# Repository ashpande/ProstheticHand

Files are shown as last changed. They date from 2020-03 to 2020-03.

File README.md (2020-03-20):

# Prosthetic Hand

This project is a prototype for an affordable, modular, myoelectric prosthetic arm. It was one of the entries for Dassault Systemes Aakruti Design contest 2019 and came among the top 3 in the south zone regionals in India among 5000+ teams. It is made out 3D printed ABS plastic and uses TPU material for joints. A detailed description of the project and its features can be found in the DIY report of this repository and the Powerpoint Presentation. All the CAD files are in SolidWorks and can be used to 3D print the prosthesis in any 3D printer.

The electronics component for myoelectric control is still under development, and the repository will be updated when it is done.

## Prosthetic Schematics

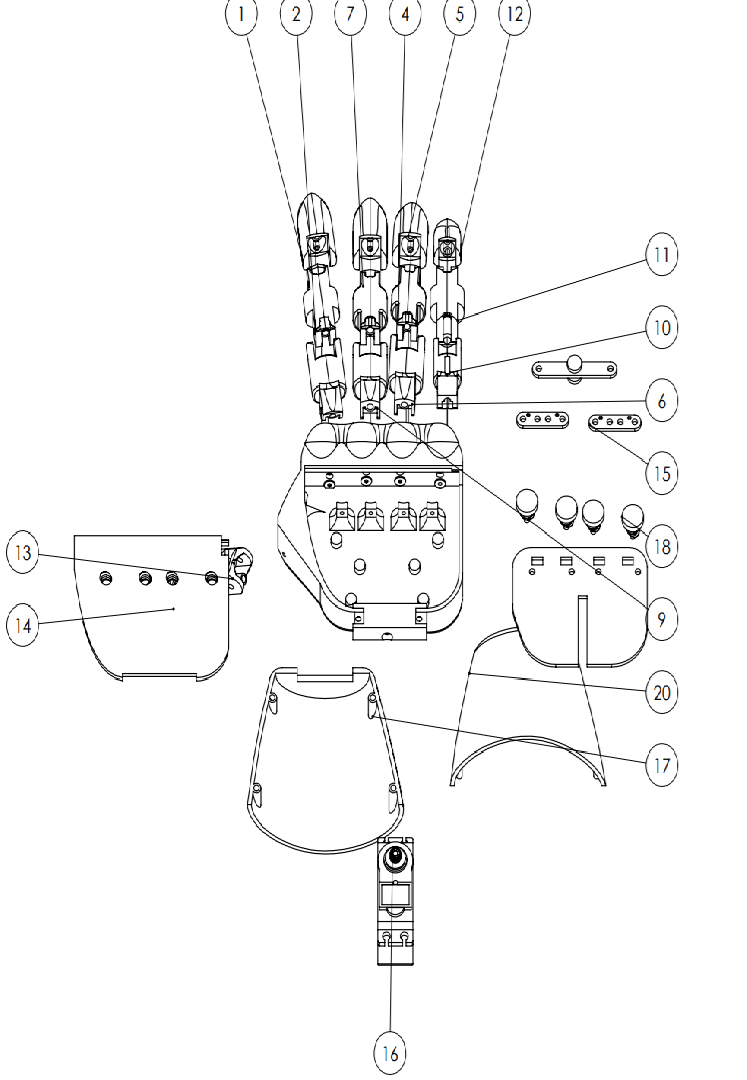
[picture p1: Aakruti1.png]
Prosthetic Hand Schematic


| Part Number | Name |
| ---| ---- |
| 1  | INDEX FINGER DISTAL|
| 2  | INDEX FINGER MIDDLE|
| 3  | INDEX FINGER BOTTOM PROXIMAL|
| 4  | RING FINGER MIDDLE |
| 5  | RING FINGER DISTAL |
| 6  | RING FINGER BOTTOM PROXIMAL |
| 7  | MIDDLE FINGER MIDDLE |
| 8  | MIDDLE FINGER DISTAL |
| 9  | MIDDLE FINGER BOTTOM PROXIMAL|
| 10 | PINKY FINGER PROXIMAL|
| 11 | PINKY FINGER MIDDLE|
| 12 | PINKY FINGER DISTAL|
| 13 | THUMB PROXIMAL|
| 14 | THUMB TIP|
| 15 | PALM FRAME BODY|
| 16 | STANDARD SERVO|

## Render
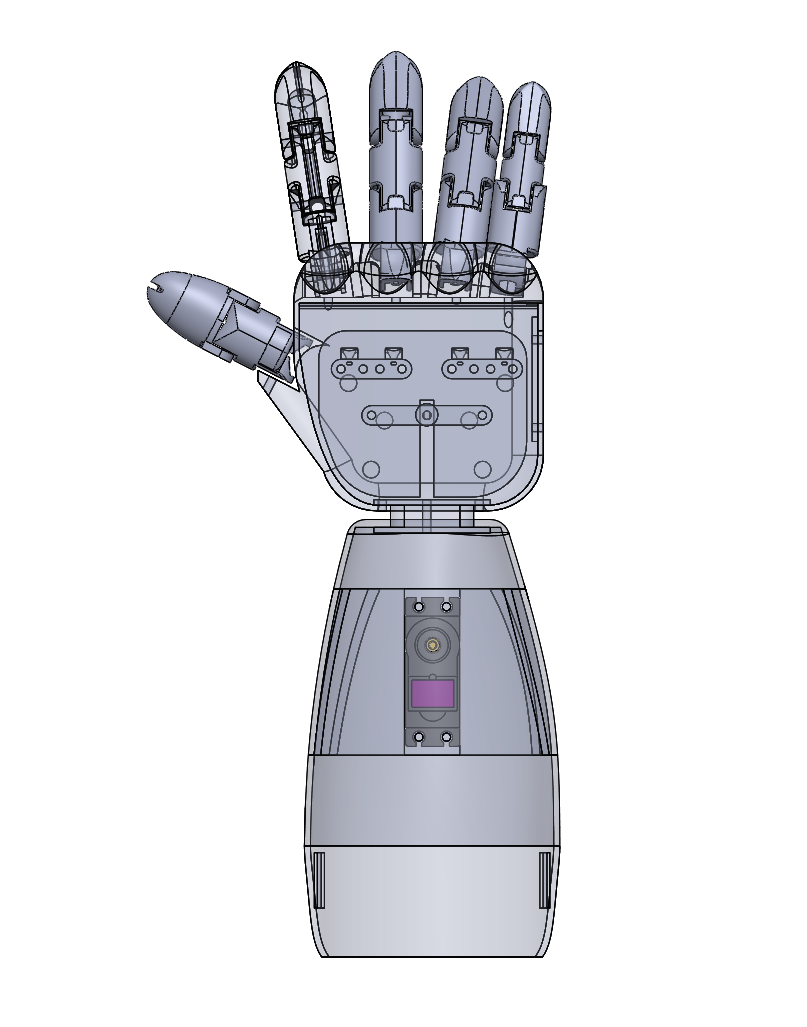
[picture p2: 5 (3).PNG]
Prosthetic Hand Render


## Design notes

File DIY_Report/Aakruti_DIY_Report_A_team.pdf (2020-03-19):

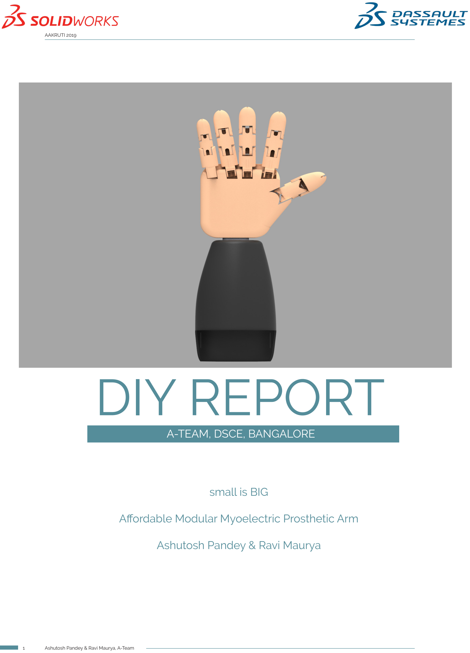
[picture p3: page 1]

1 | Ashutosh Pandey & Ravi Maurya, A-Team

AAKRUTI 2019

### A-TEAM, DSCE, BANGALORE

# DIY REPORT

### small is BIG

### Affordable Modular Myoelectric Prosthetic Arm

### Ashutosh Pandey & Ravi Maurya

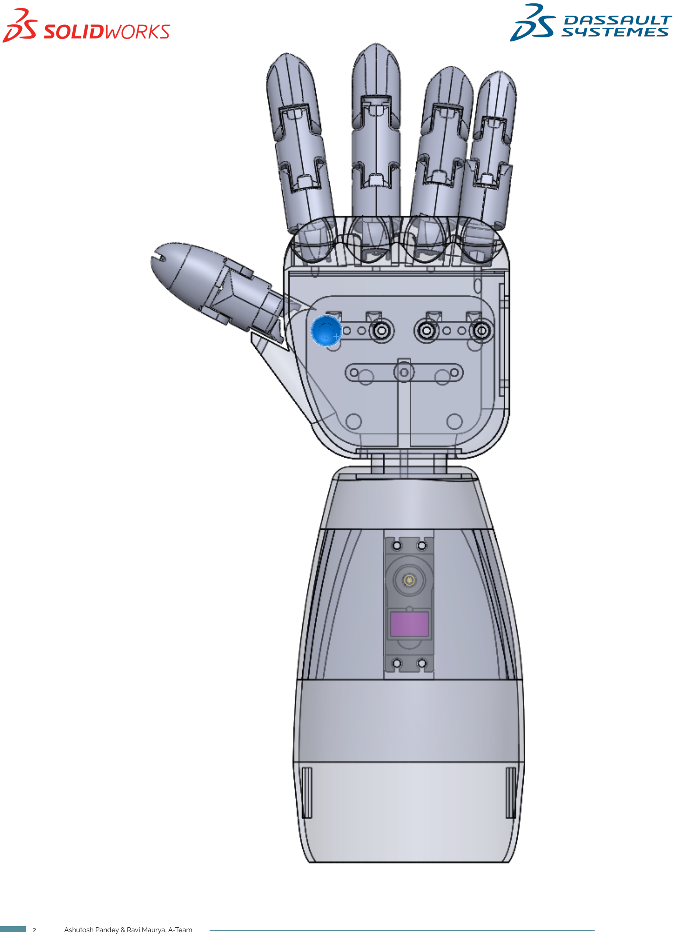
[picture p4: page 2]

### Problem Statement Market Analysis Shortcomings in Commercial Products Our Solution Design Details Product Development Cycle Analysis and Calculations Iterations of our Design Raw Materials Bill of Materials and Costing Report Electronics Assembly and Manufacturing Drawings References

## Table of Contents

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
# Problem Statement

- A multifunctional, modular, myoelectric prosthesis.

### Prosthesis

Prosthetics are artificial limbs that can be used by people who have lost their limbs, or are born with natural deformities. While the foot prosthesis has made remarkable strides in functionality and affordability with the Jaipur leg costing as little as $40, there is no such equivalent for the upper body prosthesis. Moreover, the alternatives that do exist have severe shortcomings when it comes to pinch force, grip strength and mass.

One major reason for this lack of development in upper body prosthesis is due to the complexity of the human hand itself - It has 27 degrees of freedom and it is both strong and dexterous. A need exists for an upper body prosthesis that is cheap, functional, easy to use and lightweight.

### Types of Prosthesis

There are primarily three types of upper body prosthesis in the market today:

### 1. Cosmetic Prosthesis: these prosthesis

do not offer any functionality. They are very cheap.

### 2. Body Powered: these are manipulated by

hooks and cables attached to the body. While they are also inexpensive, they require a lot of power from the user to move successfully. They also offer very little grip force and pinch strength. They are limited to opening and closing motions of the palm.

### 3. Myoelectric: these are controlled by

electrical signals from the arm stump. They do not require any force to be exerted by the user, can replicate a variety of movements but are extremely expensive ($15,000 and up).

# 50 lakh

### amputees in

India.

₹1.5 L

### Cost for a semi functional

prosthesis.
50%

### people don’t wear their pros-

thesis regularly.

27

### Degrees of Freedom in the

human hand.

400 g

### Average weight of a human

hand.

The Global Prosthesis Market According to a survey by Future Market Insights (FMI), upper body prosthesis are predicted to grow at a Compounded Annual Growth Rate (CAGR) of 4.8 %. The market is primarily dominated by 4 companies: Ottobock, Ossur, Fillauer and Blatchford.

North America and Europe account for 55% of the sales, while India makes up less than 10% of the current $330 million upper body prosthesis market. This despite India having over 50 lakh amputees, and adding over 24,000 new amputees every year, shows that the uptake of upper arm prosthesis in India has been very slow.

The current offerings in the market are prohibitively expensive, In USA a part of the prosthesis cost is borne by the Insurance companies, despite this the costs go from $15,000 to over $90,000. The cheapest Indian alternatives also cost over ₹1.5 Lakh, putting them out of reach of economically disadvantaged individuals who lose out on their livelihoods due to their disabilities.

25% of the demand is for below the elbow prosthesis, while the demand for myoelectric prosthesis is 40%.

In India a few popular options are the Ottobock Body powered arm that uses hooks and cables and costs ₹1.5 lakh, the Myofacil Myoelectric arm that costs ₹2,36,000 and can perform a few movements after training, and the upper segment has the Bebionic prosthetic arm, which costs over ₹10,00,000 and can replicate lots of movements.

# Market Analysis

- A global 1.2 billion USD market for prosthesis exists.

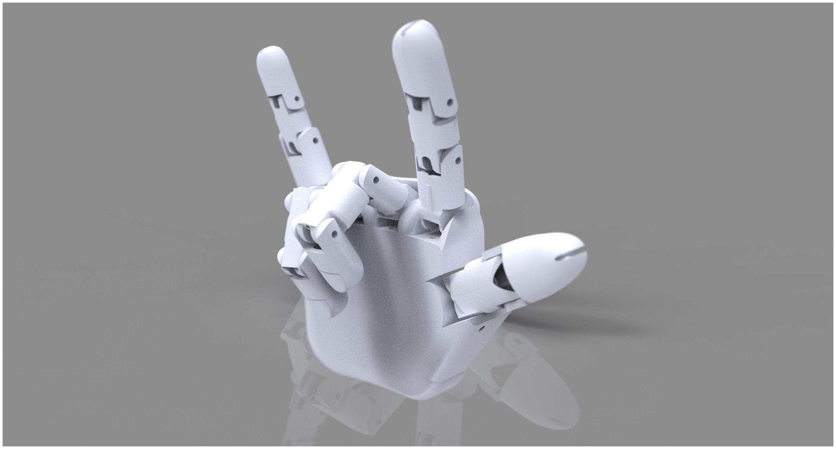
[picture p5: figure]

Modern day prosthesis are
plagued by a whole host
of problems apart from the cost, we shed some light on these shortcomings below:

Pinch Force and Grip
Strength: a person needs
to be able to lift objects with their prosthetic arm. Studies recommend a bare minimum of 45N of grip force,
with 65N being the optimum.

Weight: The average human

hand weighs 400 grams.
Myoelectric prosthesis can weigh upto 1.5Kg, which
makes them too uncomfortable to use and wear for extended periods of time.

Cost: Unlike the ubiquitous Saathi and Jaipur leg, there is no cheap upper arm prosthesis in India. The most
common type of prosthetics used by Indians are the cosmetic ones, which help
with the social stigma but do not objectively improve the quality of life.

Non Modular: Upper arm
prosthesis tend to wear out in 5 years. This makes them an expensive, recurring investment. The tips of the fingers are particularly prone to wear and tear, and currently the entire prosthesis must be replaced in such a case. Moreover, children often outgrow their prosthesis and have to buy new ones.

An average hand can exert upto 95 N of force in a precision grip. For a prosthesis to be functional, it has to be able to manage atleast 50% of that grip strength, which almost all prosthesis fail to do. There has been very little progress in upper arm prosthesis research in 40 years.
- Study by TU Delft.

# Shortcomings

## - In the current market offerings

Our product costs less than ₹15,000 to manufacture using 3D printing technology which is fast becoming ubiquitious in India. It is lightweight - weighing in at only 372 grams. This is made possible by the use of generative design in the fixtures. We use cheap, off the shelf myoelectric sensors and make the design modular to be able to easily replace worn out parts.

### 32 distinct combinations

Our whiffletree mechanism
allows our arm to have 32
distinct combinations of
positions.

Modularity
Our arm consists of distinct modules which can be easily swapped out.

Myoelectric control
We use myoelectric control powered by an inexpensive
sensor to make the product easy to use.

# Our Solution

- A multifunctional, modular, myoelectric arm.

Our Product
We studied the various prosthesis in the market, referred to research papers by leading universities and medical journals, and finally chose to use 3D printing technology for our prototype because it allows us to quickly test out variations of the design.

Keeping the Indian weather conditions in mind, ABS was chosen as the material because of its greater tolerance to heat and higher strength.

The Whiffletree is a mechanism to distribute force evenly through linkages. In our prosthesis, it allows us to make different positions and combinations using only 1 servo and that is the reason it was chosen.

Keeping the weight low was important to making the product more useable and to reduce cost. We used generative design in the servo fixtures to reduce the weight.

Body powered prosthesis require a lot of hooks and cables, and ultimately provide a worse user experience because they require so much force to operate. Keeping this in mind, we decided to opt for myoelectric control over making a purely mechanical design. We used commercially available components to bring down the cost and reduce the time to market.

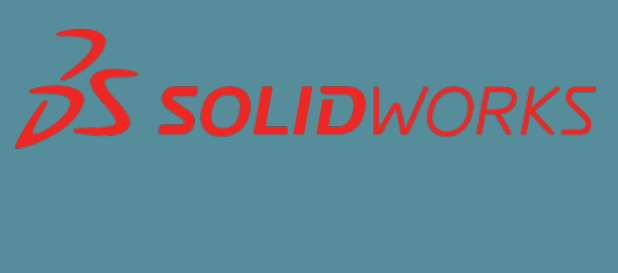
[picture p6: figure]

Fingers
One single finger was the
starting point for the entire design process. The human
hand consists of four similar fingers and one thumb, it was logical to conclude that the finger design could potentially be replicated four times. The finger design process began with determining what motion was required
for each finger. The human hand was simply viewed
gripping various household objects such as a cup and
marker commonly found in
a person’s daily routine. The location of the various joints were measured and translated to drawings.
The human finger is an
amazing piece of engineering consisting of three individual pivot joints which can almost be individually actuated through muscular tendons.

The Thumb
The thumb has also been
designed in a similar fashion. Most commercial and research prosthetic hands
aim to provide at least three degrees of freedom in the
thumb.
This thumb however only
provides a two degrees of
freedom – it can only open/ close in a single way. Guide holes have been incorporated into the design of the fingers and thumb to optimise tendon orientation and prevent the tendon lines from getting caught on a sharp
edge.

The Palm
Each finger connects to the palm by pins. The palm accommodate:
1) the finger base frames,
2) the selectively lockable differential mechanism

The design of the proposed differential mechanism is
motivated by the fact that humans develop over their
lives a tremendous ability to select the most appropriate grasping strategy for a given task. A well known differential mechanism is the whiffletree , which is typically used to interconnect the
index, middle, ring and pinky fingers of underactuated,
multifingered robot
hands.

# Design Details

## We use a bottom-up design methodology

### The Fingers

are the basic unit of
articulation.

### The Thumb

Humans have opposable
thumbs.

### The Palm

Houses the selectively lock- able differential mechanism.

### Fingers

4

### Thumb

1

### Palm

1

The prototype went through iterations where it was tested, upgraded and independently ana- lysed critically. This helped us make the end product lighter, more efficient and easier to use and maintain.

# Identify the problem

Market Value | Responsibility

Our product design cycle
starts with research into
the problem statement.

### Effectiveness

How effective are the solutions in the market? Do
they adress the need of
the users? is there scope
for improvement?

Different Approaches
What are the dif- ferent design phi- losophies that can

be used? Different
m a n u f a c t u r i n g
processes?

Scalability

How labour inten- sive is the manu- facturing process?

Can it be mass
produced easily?

Upgradeability

Can the product
be easily upgrad- ed? Can it be done

in a cost effective
manner?

Profit

Can the product
be sold for a sus- tainable profit?

Does the revenue
model account for
losses?

Is there an untapped
market for the product?
How much is the industry worth currently? Is the product going to increase
in demand?

Does the product help improve the quality of life for its users? Can it be sold
ethically without short
changing the consumer?

# Product Development Cycle

## A few questions that we asked ourselves

# Calculations

The weight that could be supported by the fingers was calculated.

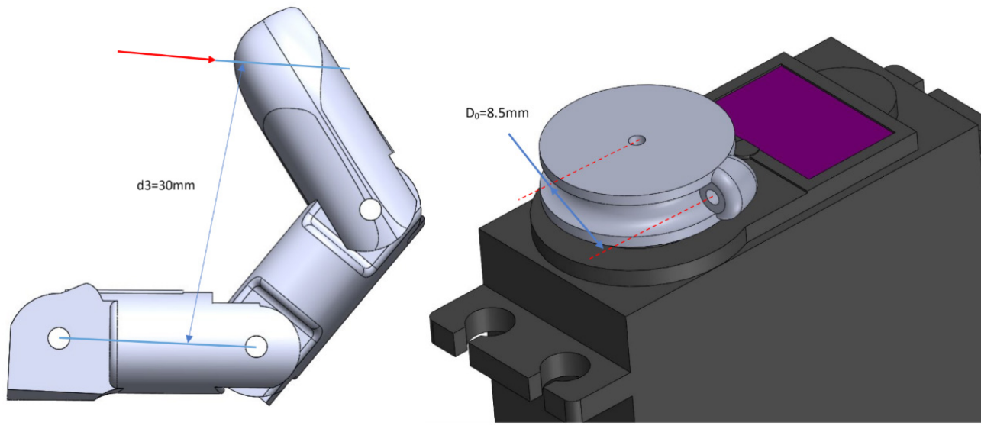
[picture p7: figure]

135 grams is the mass that each finger can lift when it is fully extended. When the fist is closed, the force applied to the index finger acts normal to it, and each finger can lift a total of 320 grams for a lifting capacity of 1280 grams.

When the finger is fully extended, force is applied at the tip (distal) end of the finger. The movement is given by the expression:

The given torque of the servo we use:

Tendon creates a moment about each joint in the finger. Since knuckle joint is the furthest from the applied force the moment about it will be the greatest. At maximum lift M1=M2. The stall torque (maximum turning force) of the OC Servo A091 is 9Kg-cm at 6v. This stall torque will be transferred equally in all 5 fingers.

135 grams is the mass that each finger can lift when it is fully extended. When the fist is closed, the force applied to the index finger acts normal to it, and each finger can lift a total of 320 grams for a lifting capacity of 1280 grams.

# Analysis

- We confirmed our hand calculations with analysis.

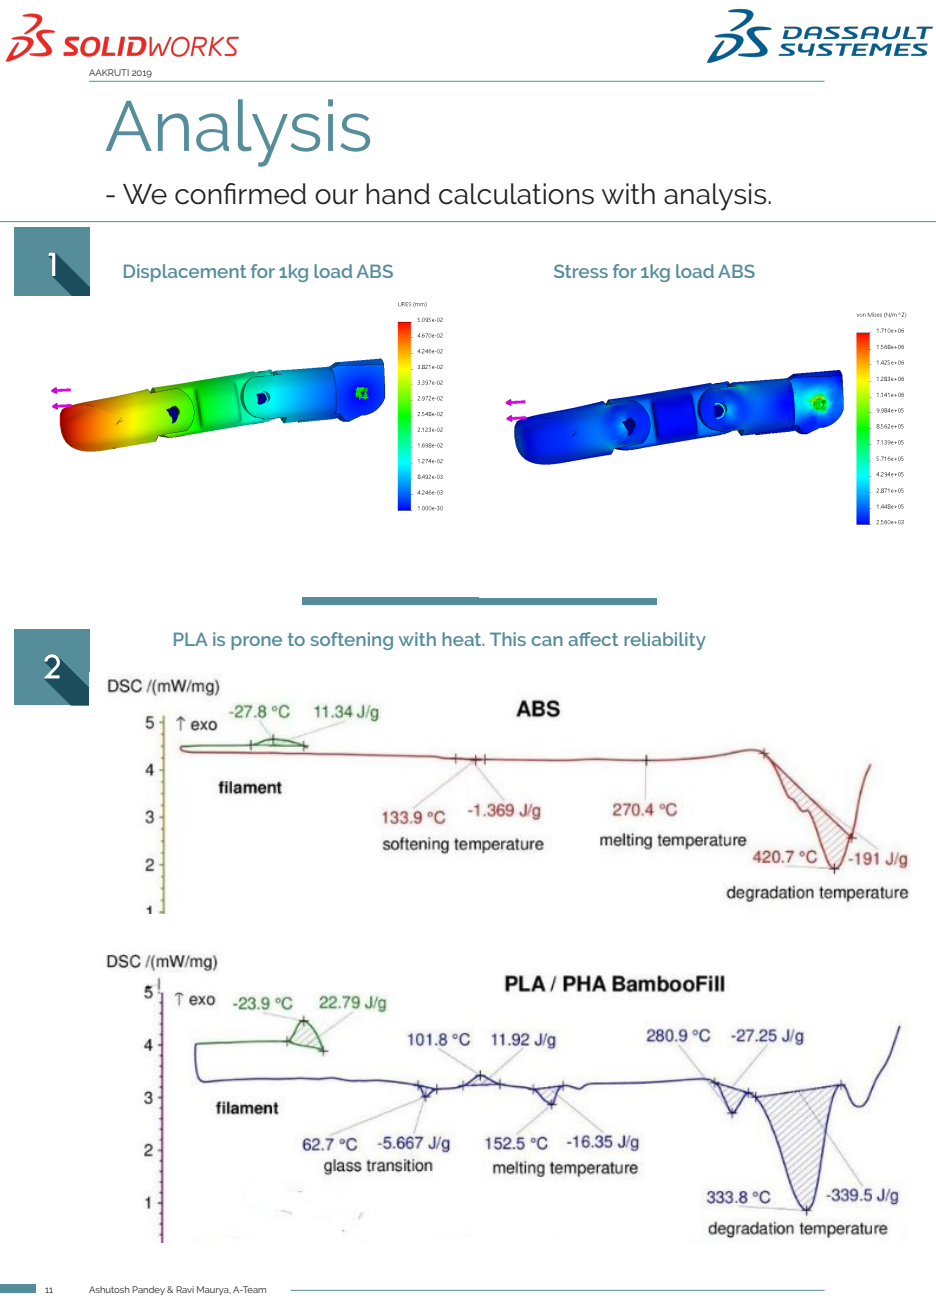
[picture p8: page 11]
Displacement for 1kg load ABS; Stress for 1kg load ABS

PLA is prone to softening with heat. This can affect reliability

# Design Iterations

## - 3 prototypes were made in total

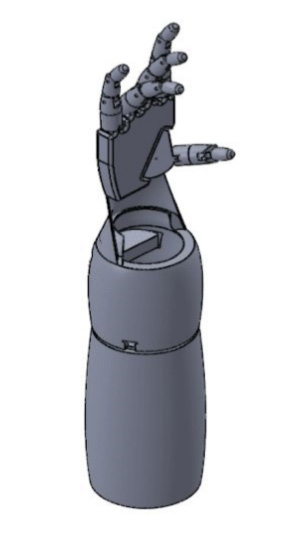
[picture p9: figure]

The First Prototype

The first prototype was made for the initial concept submission phase. This prototype had the following shortcomings/features:
- The prototype could only open/close the fist.
- There were no buttons or whiffletree mechanism.
- The 5 fingers were directly connected to different servos.
- It was rather heavy 725 grams.

The Second Prototype

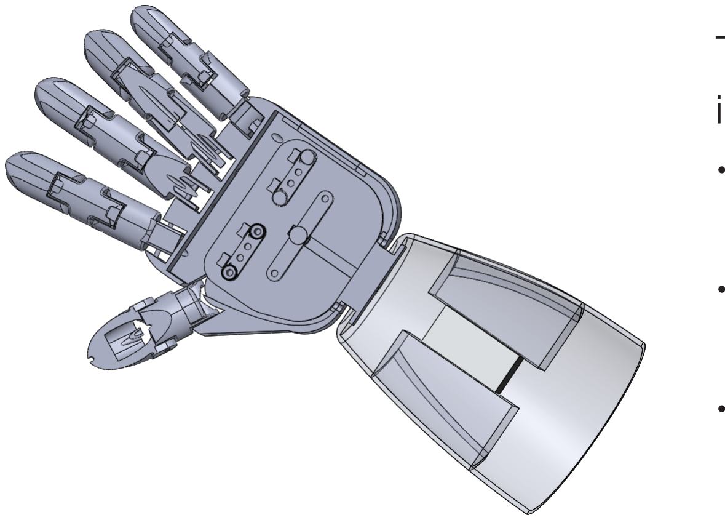
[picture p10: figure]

The second prototype was made for the zonal round in Chennai. This prototype featured improvements:
- The whiffletree mechanism was chosen to reduce the complexity of the electronics.
- TPU material was chosen for the joints to act as tendons, because of its elasticity and durability.
- During manufacturing it was found that the fingers needed repositioning and tolerances were needed.

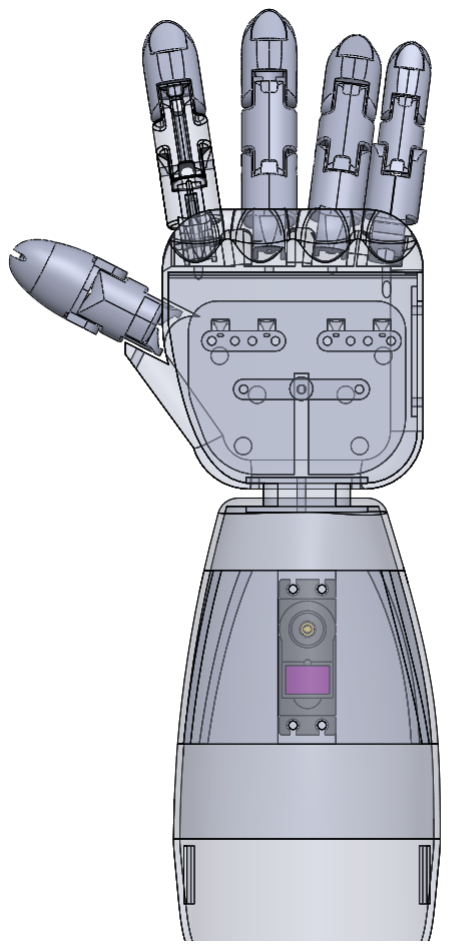
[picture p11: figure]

The Third Prototype

The third prototype was made for the finals of Aakruti 2019. This features a number of improvements over the second version:
- The fingers were repositioned to make them move more freely.
- Tolerances were considered during 3D printing to make manufacturing easier.
- The thumb was redesigned to have means to connect to a second servo, as the human thumb is opposable and free to move and thus, operates independently of the rest of the hand.

# Raw Materials

## - After much experimentation, we chose these

ABS - Acrylonitrile Butadiene Styrene

z High Strength

z High Glass Transition temperature

z Smooth Finish and can be 3D print

TPU - Thermo Plastic Polyurethane

z Used as an artificial tendon

z Flexibility and elasticity

z Durability- lasts a long time

Nylon Thread

z To transfer force from the servo to fingers

z Resistant to heat

z Durable

Acetone

z Is used to work the ABS to a smooth finish.

Cyanoacrylate Glue

z To glue together different components,

z Cures fast.

z Strong bond.

# Bill of Materials

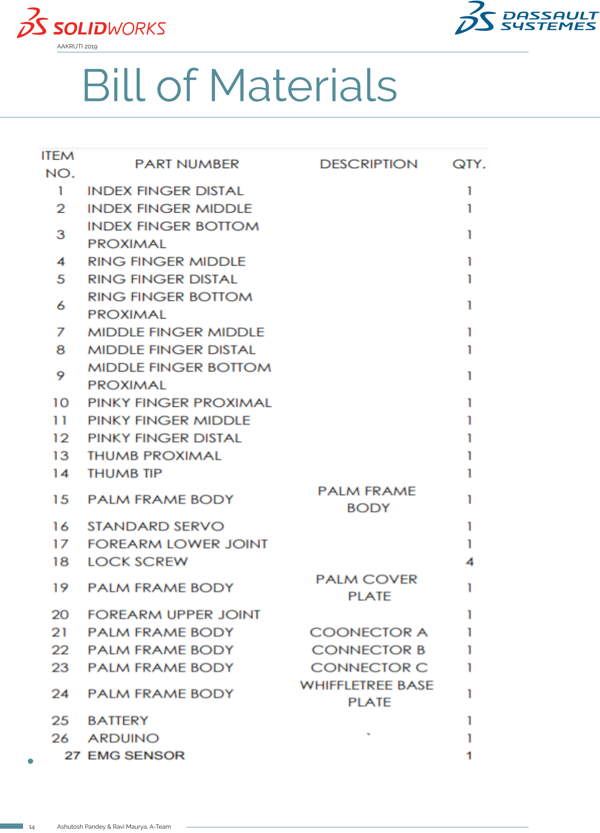
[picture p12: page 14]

z

# SolidWorks Costing Report

# EMG

Electromyography is used to read signals from the arm.

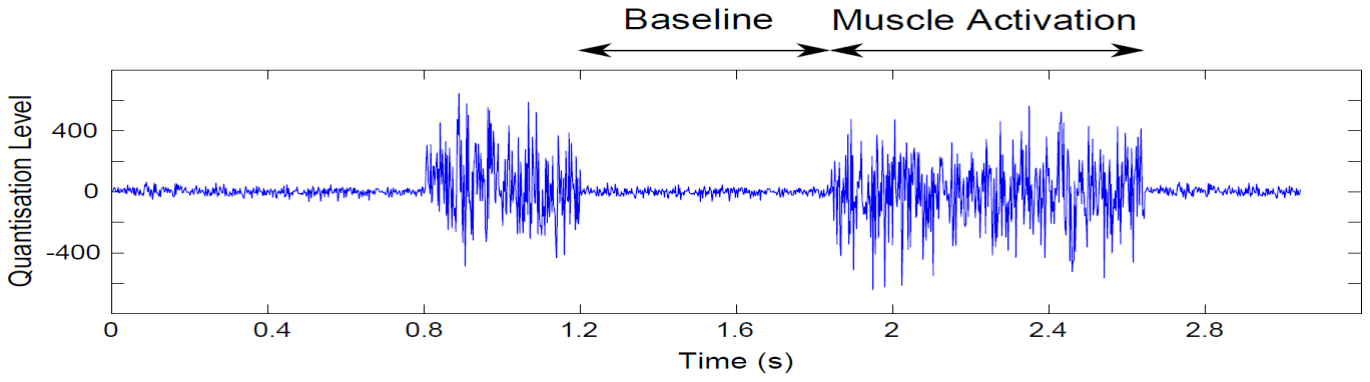
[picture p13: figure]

All animals have muscles that contract by means of electrical activity - it is well known that the brain sends electrical impulses to the motor neurons in the arm which causes muscle fibers to contract. It is easy to measure this contraction of muscle fibers from surface electrodes, this is known as electromyography.

Procedure
For the purpose of the prototype, we use a Myoware sensor which costs $37. The sensor has a pair of snap on electrodes attached to it. Currently these electrodes are one time use only - we are undertaking research on how to use reusable electrically conductive cloth.

The electrodes are placed at specific spots above the stump of the arm. There are three electrodes - Two electrodes at the ends of a muscle fiber, and one reference electrode which is normally attached to the underside of the arm.

When the consumer flexes their arm, it generates an electrical signal that is picked up by the sensor.

The sensor is connected to a microcontroller, which processes the signal and controls a servo. Practically any microcontroller can be used for this, although we use an AT-MEGA328P as it is common, cheap and fast enough to do the job real time.

The servo we use is a high torque 9kg-cm servo that provides the prosthesis a lifting capacity of upto 1.3 kg, this is no mean feat as n0rmal prosthesis are able to lift nowhere near this amount.

The whole setup is powered by a battery, at full load the system can last around 8 hours of use on a 2200 mAh battery. The battery can be recharged at night when the prosthesis is disengaged.

Electromyography is an electrodiagnostic medicine technique for evaluating and recording the electrical activity produced by skeletal muscles. In our prototype, we use EMG Sensors attached to the stump of the arm and measure the change in potential with contraction of muscle fibers, and use this signal to control our prosthetic hand.

# Circuit Diagram

The following circuit diagram is made on fritzing.

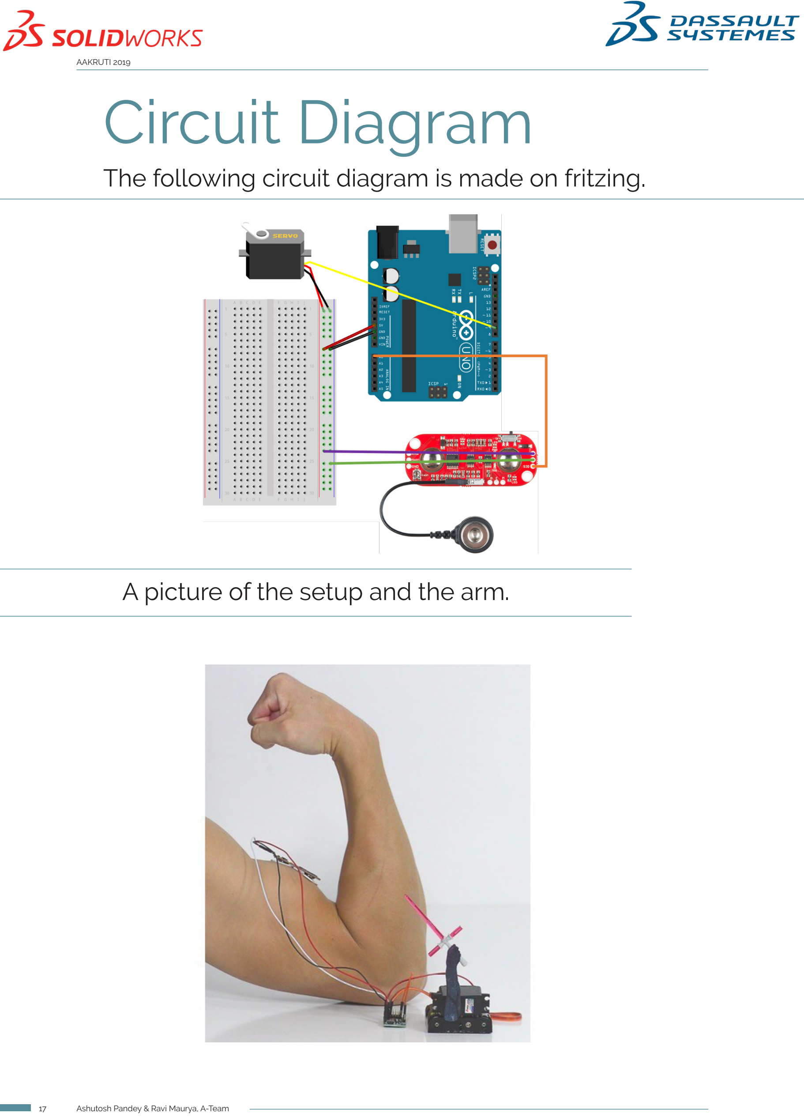
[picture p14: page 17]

A picture of the setup and the arm.

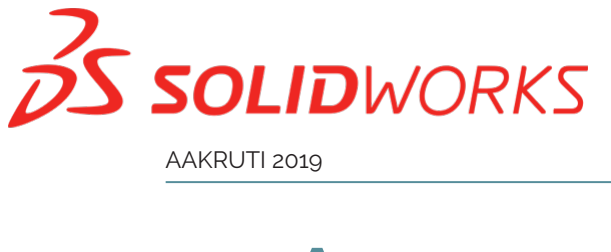
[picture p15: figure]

# Assembly

- Each finger consists of
three individual printed parts connected by
polypropylene pins. all
the 4 fingers along with

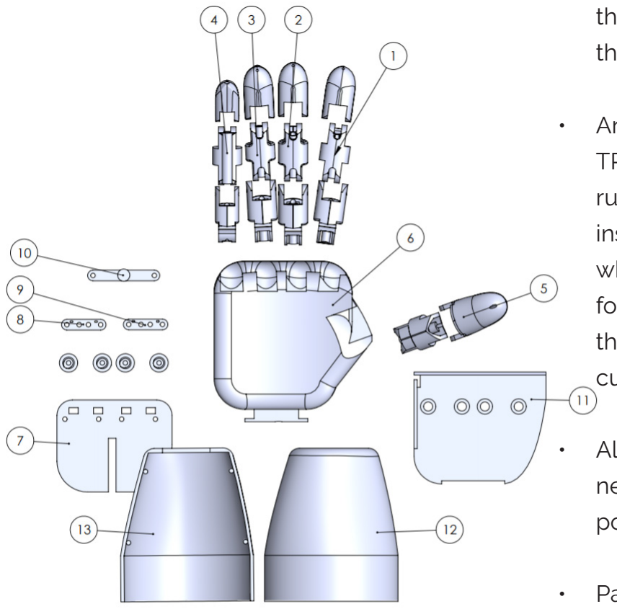
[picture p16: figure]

thumb are connected in
the same way.
- Artificial tendon loops of TPU and nylon thread
runs through channels
inside the finger which
when pulled rotational
forces are applied to all
the joints and fingers
curls up.
- All the fingers are connected to the palm by
polypropylene/abs pins.
- Palm accommodates
the differential mechanism (Whiffletree mechanism) Which consists of
the component such as
bar A(8) and bar B (9).
- Bar A connects index and

middle finger whereas
bar B concepts ring and
pinky.
•
- The top two bars of our
whiffletree have appropriately designed holes
and the palm accommodates a set of buttons
that upon pressing are
elongated.
- When | a | button | is
pressed the elongated
part fills the corresponding finger hole and the
motion of this particular
finger is constrained.

# Manufacturing Drawings

1 | 2 | 7 | 4 | 5 | 12

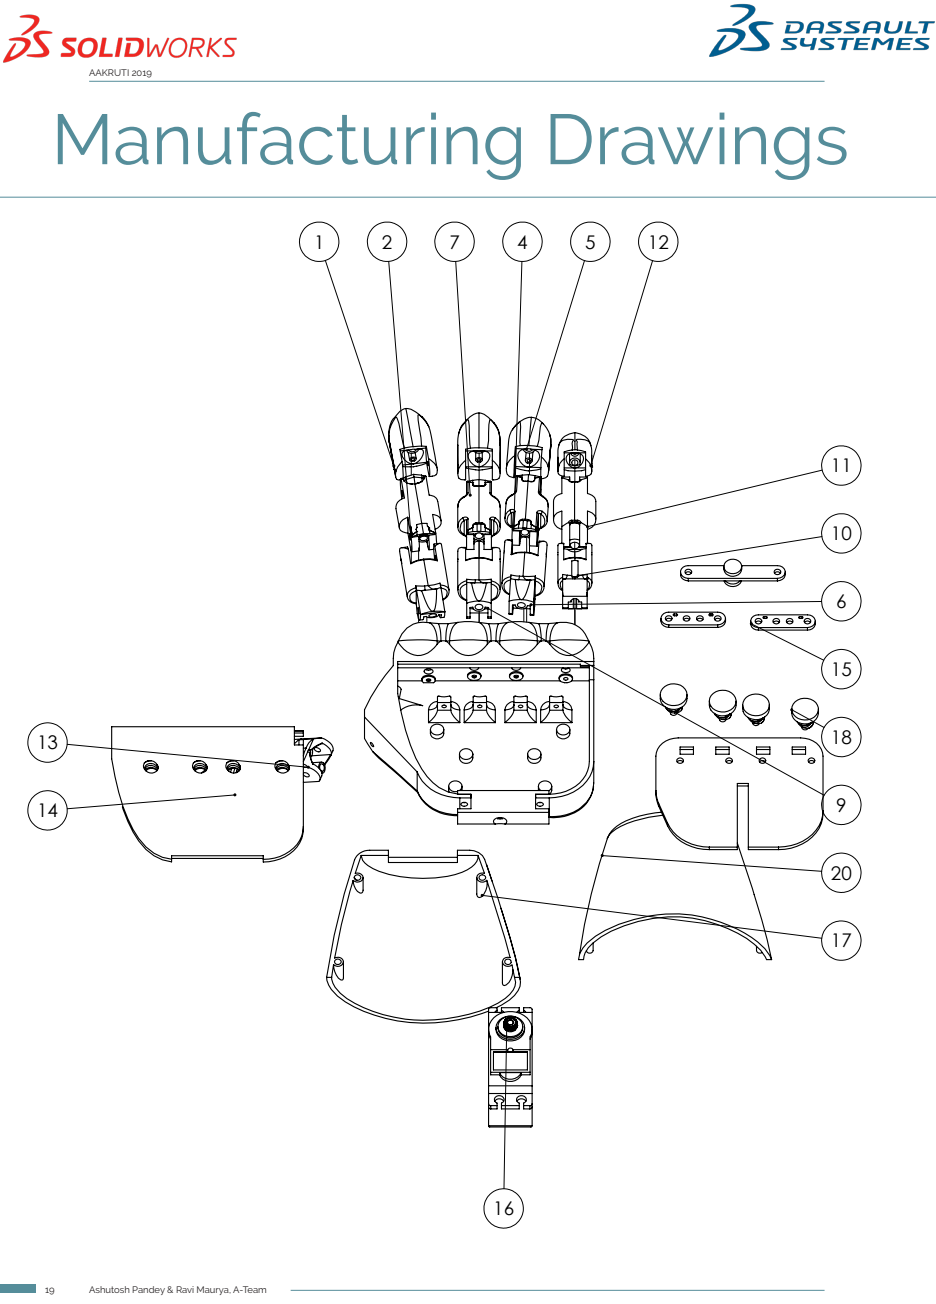
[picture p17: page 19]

# Manufacturing Drawings

## ITEM

NO. | PART NUMBER | DESCRIPTION | QTY.
1 INDEX FINGER DISTAL | 1
2 INDEX FINGER MIDDLE | 1

## 3 INDEX FINGER BOTTOM

| PROXIMAL | | 1
4 RING FINGER MIDDLE | 1
5 RING FINGER DISTAL | 1

## 6 RING FINGER BOTTOM

| PROXIMAL | | 1
7 MIDDLE FINGER MIDDLE | 1
8 MIDDLE FINGER DISTAL | 1

## 9 MIDDLE FINGER BOTTOM

| PROXIMAL | | 1
10 PINKY FINGER PROXIMAL | 1
11 PINKY FINGER MIDDLE | 1
12 PINKY FINGER DISTAL | 1
13 THUMB PROXIMAL | 1
14 THUMB TIP | 1
15 PALM FRAME BODY | PALM FRAME
| | BODY | 1
16 STANDARD SERVO | 1
17 FOREARM LOWER JOINT | 1
18 LOCK SCREW | 4
19 PALM FRAME BODY | PALM COVER
| | PLATE | 1
20 FOREARM UPPER JOINT | 1
21 PALM FRAME BODY | COONECTOR A | 1
22 PALM FRAME BODY | CONNECTOR B | 1
23 PALM FRAME BODY | CONNECTOR C | 1
24 PALM FRAME BODY | WHIFFLETREE BASE
| | PLATE | 1
25 BATTERY | 1
26 ARDUINO | ` | 1

# Manufacturing Drawings

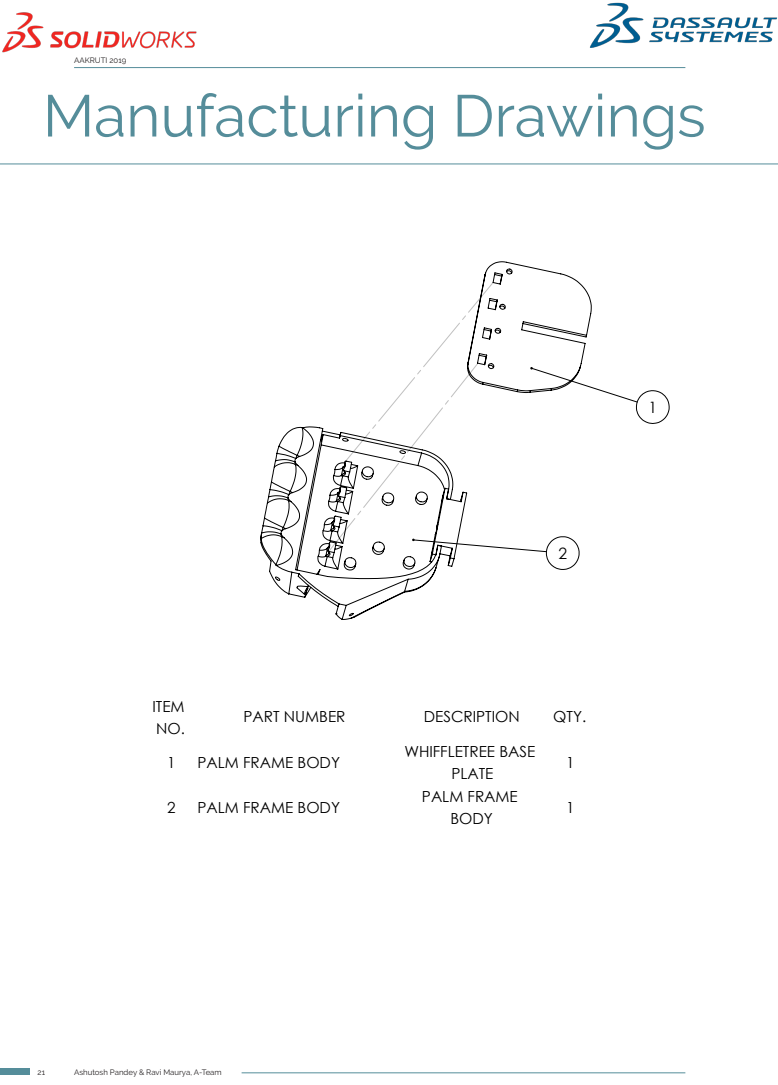
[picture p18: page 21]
ITEM; PART NUMBER; DESCRIPTION; QTY.; 1 PALM FRAME BODY; WHIFFLETREE BASE; PLATE; 2 PALM FRAME BODY; PALM FRAME; BODY

# Manufacturing Drawings

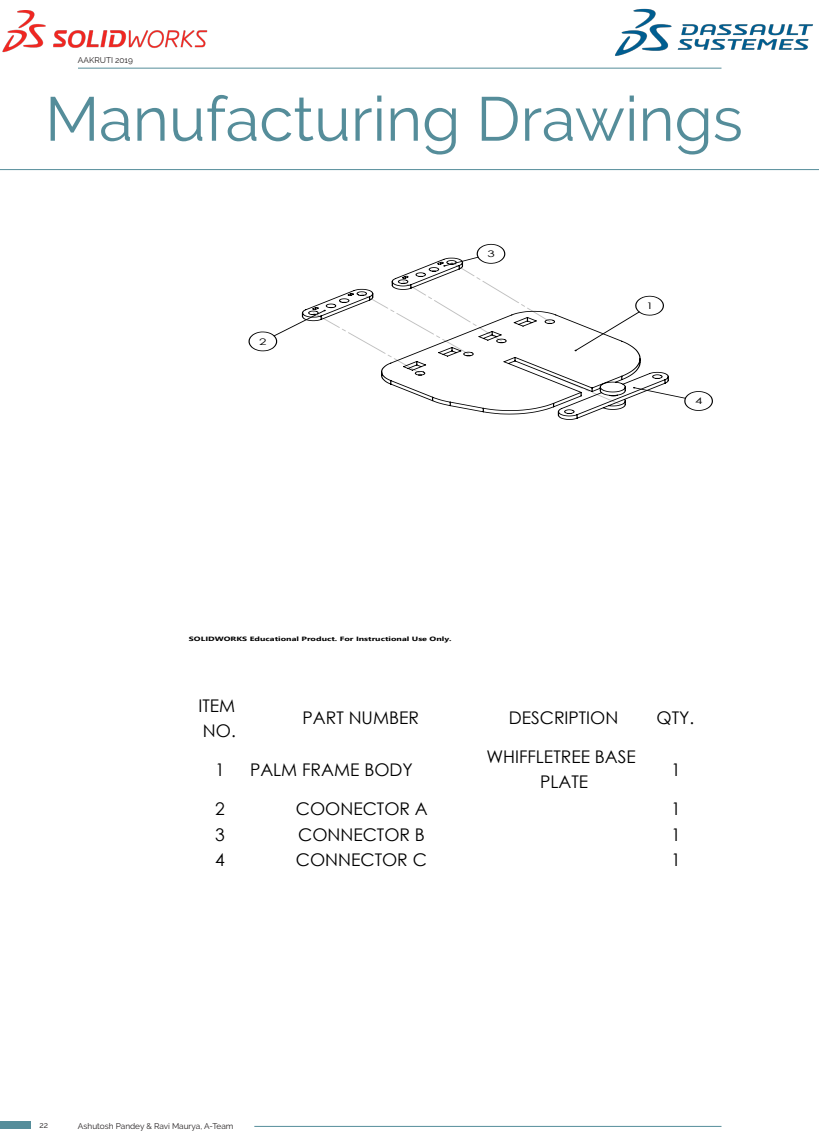
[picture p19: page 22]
ITEM; PART NUMBER; DESCRIPTION; QTY.; 1 PALM FRAME BODY; WHIFFLETREE BASE; PLATE; COONECTOR A; CONNECTOR B; CONNECTOR C

SOLIDWORKS Educational Product. For Instructional Use Only.

# Manufacturing Drawings

2

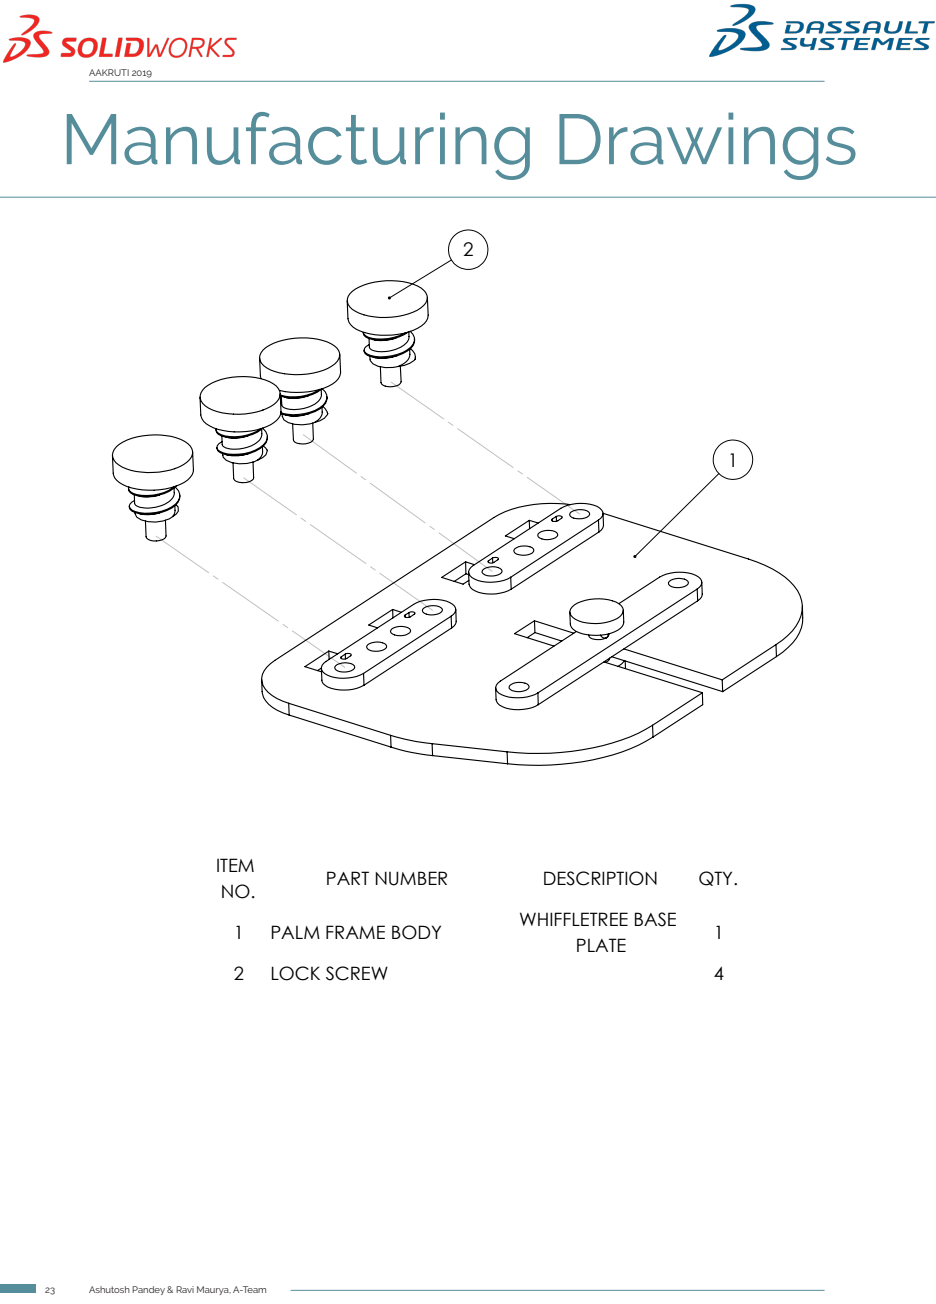
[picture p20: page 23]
ITEM; PART NUMBER; DESCRIPTION; QTY.; 1 PALM FRAME BODY; WHIFFLETREE BASE; PLATE; 2 LOCK SCREW

# Manufacturing Drawings

1

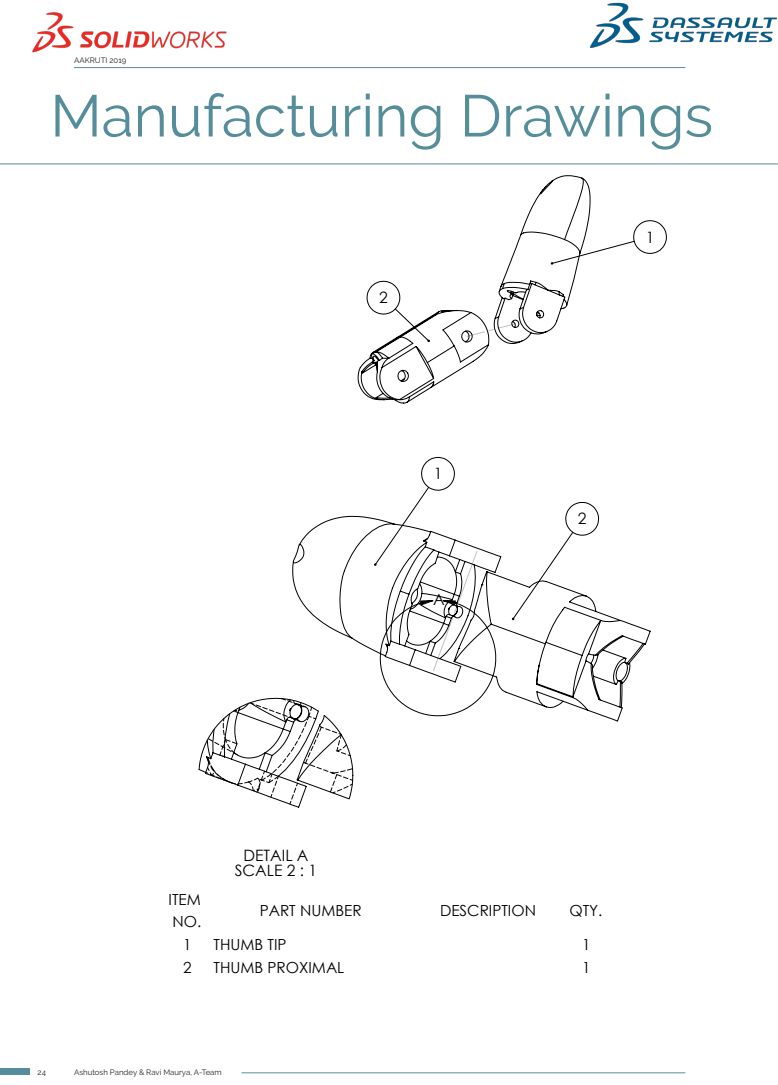
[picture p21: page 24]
ITEM; PART NUMBER; DESCRIPTION; QTY.; 1 THUMB TIP; 2 THUMB PROXIMAL; DETAIL A SCALE 2 : 1

# Manufacturing Drawings

1

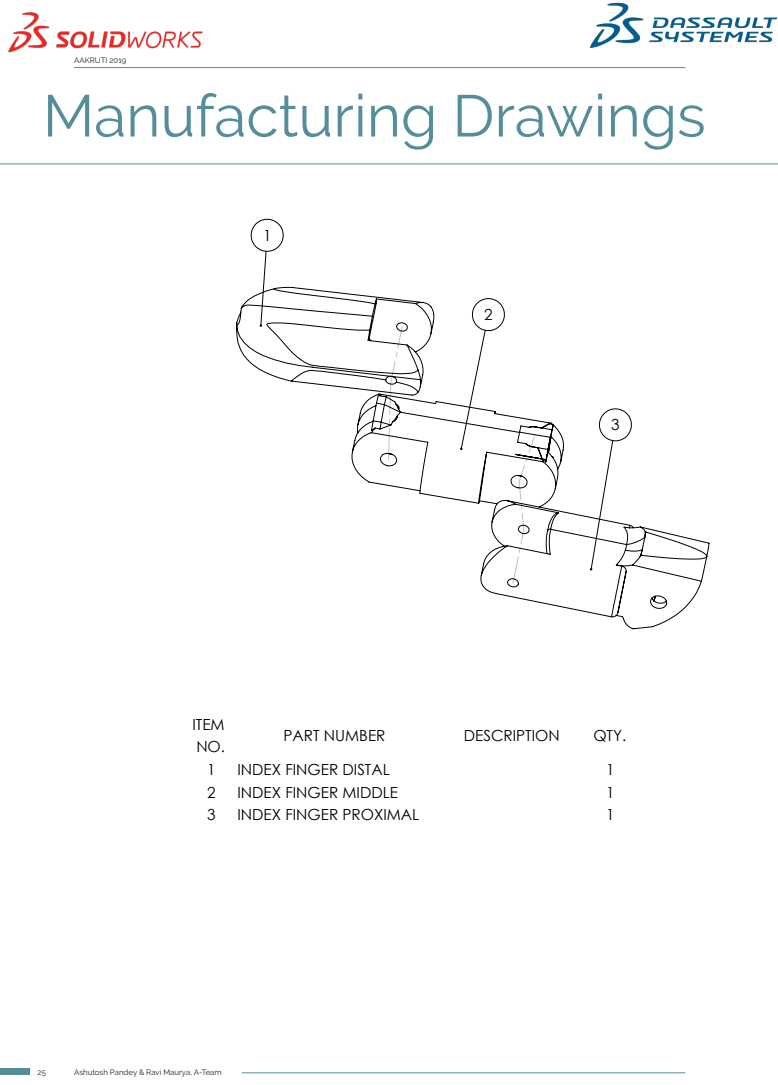
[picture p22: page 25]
ITEM; PART NUMBER; DESCRIPTION; QTY.; 1 INDEX FINGER DISTAL; 2 INDEX FINGER MIDDLE; 3 INDEX FINGER PROXIMAL

# Manufacturing Drawings

1

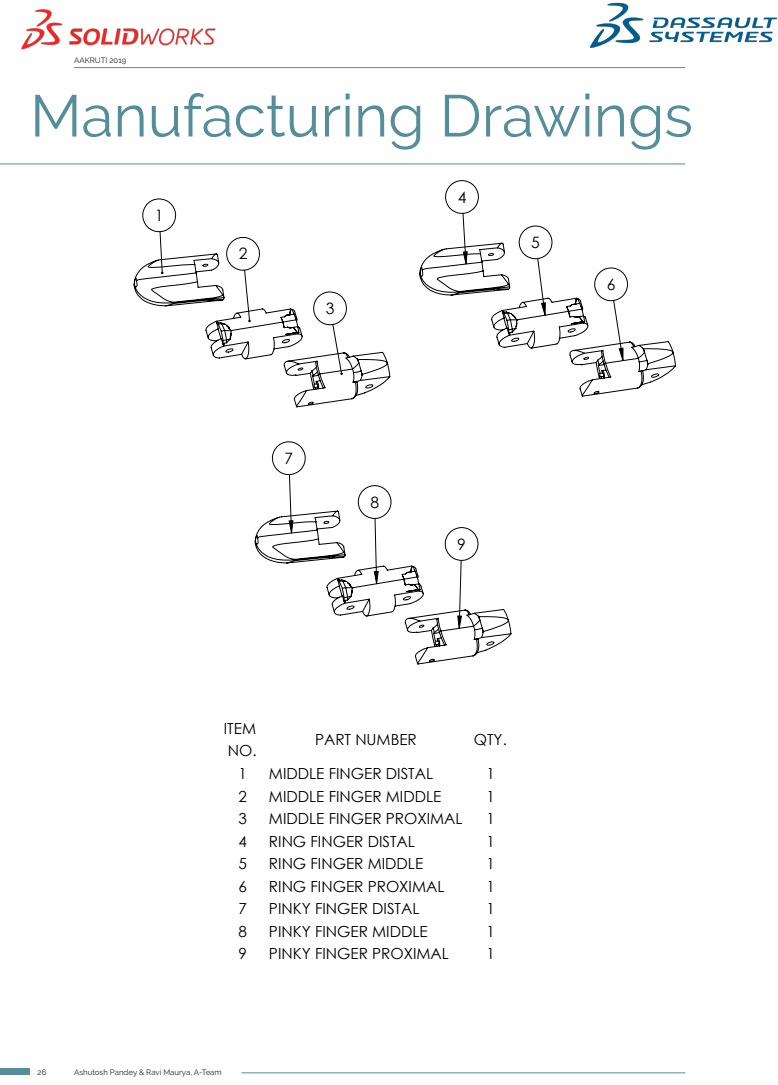
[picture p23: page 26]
PART NUMBER; QTY.; 1 MIDDLE FINGER DISTAL; 2 MIDDLE FINGER MIDDLE; 4 RING FINGER DISTAL; 5 RING FINGER MIDDLE; 6 RING FINGER PROXIMAL; 7 PINKY FINGER DISTAL; 8 PINKY FINGER MIDDLE; 9 PINKY FINGER PROXIMAL

ITEM
3 MIDDLE FINGER PROXIMAL 1

# Manufacturing Drawings

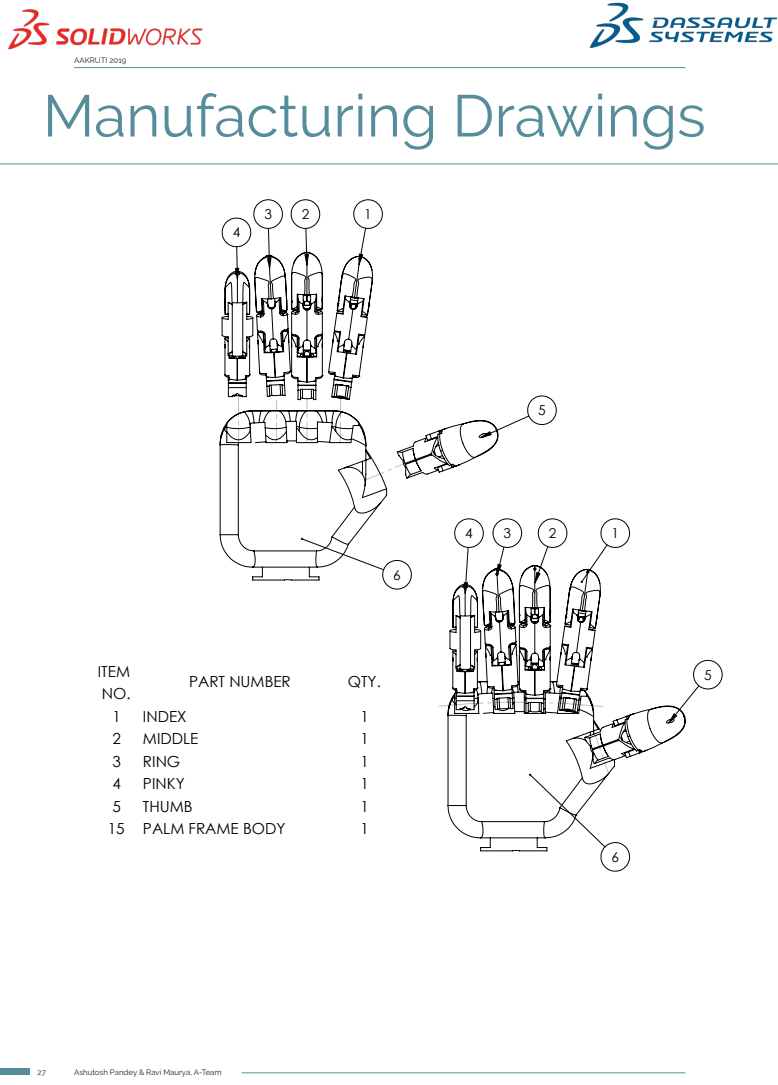
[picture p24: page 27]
ITEM; PART NUMBER; QTY.; 1 INDEX; 2 MIDDLE; 3 RING; 4 PINKY; 5 THUMB; 15 PALM FRAME BODY

# Manufacturing Drawings

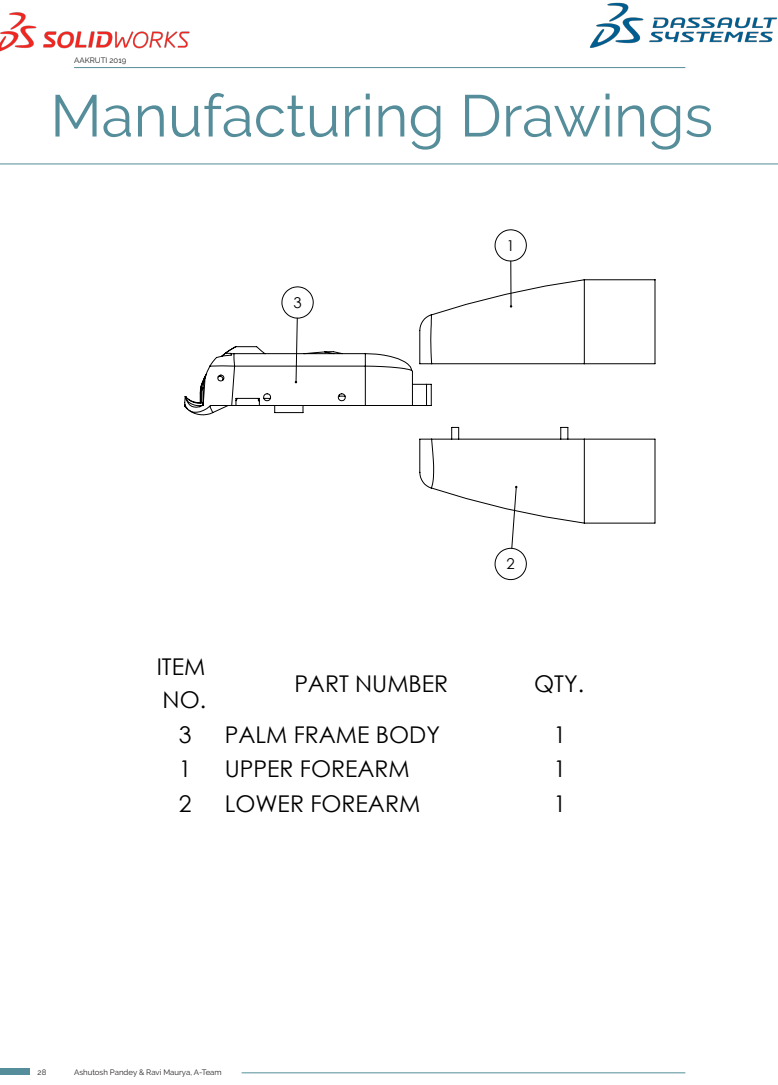
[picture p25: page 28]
ITEM; PART NUMBER; QTY.; 3 PALM FRAME BODY; 1 UPPER FOREARM; 2 LOWER FOREARM

# Manufacturing Drawings

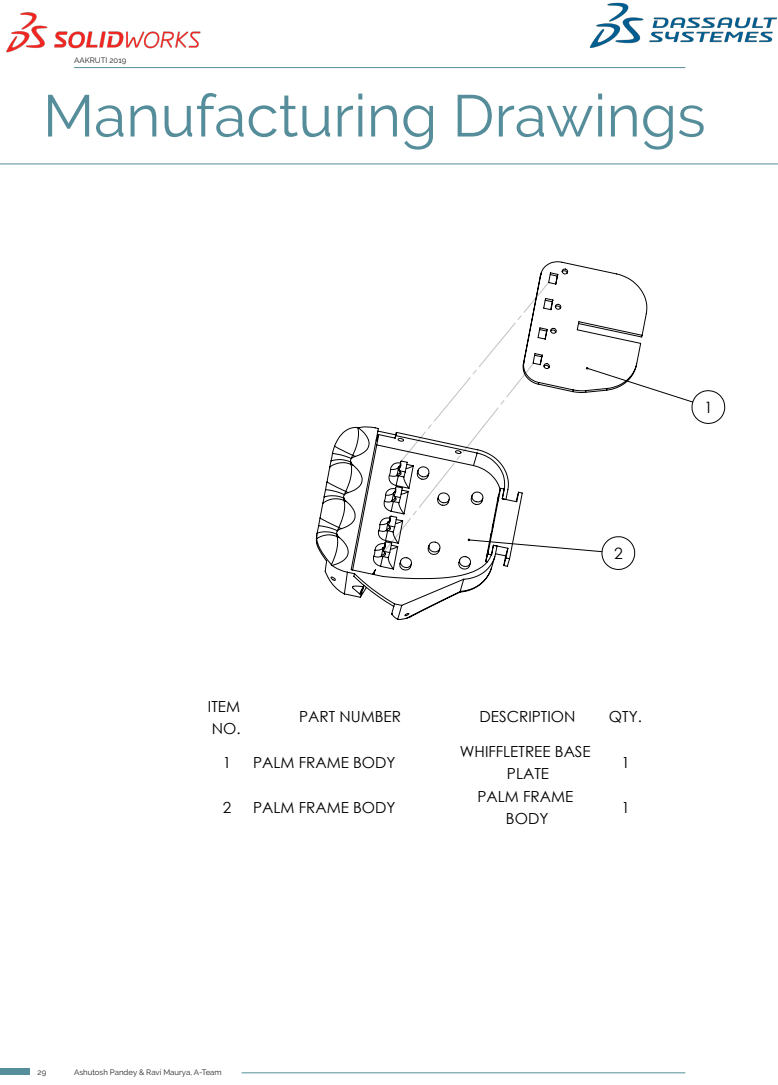
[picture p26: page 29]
ITEM; PART NUMBER; DESCRIPTION; QTY.; 1 PALM FRAME BODY; WHIFFLETREE BASE; PLATE; 2 PALM FRAME BODY; PALM FRAME; BODY

# References

https://www.ottobock.in/prosthetics/upperlimb/solution-overview/myofacil-prosthesis-system/

https://singularityhub.com/2010/06/30/howmuch-is-the-newest-advanced-artificial-hand-11000-usd-video/

https://www.livestrong.com/article/468905-hand-grip-strength-test/

https://biology.stackexchange.com/questions/30857/does-the-human-hand-have-27-degrees-of-freedom

https://www.hindustantimes.com/delhi-news/customised-high-end-prosthetics-that-don-tburn-a-hole-in-your-pocket/story-a6p6VtyVzuXjwPriSrOhNO.html

https://www.amrita.edu/news/research-paperamrita-prosthetic-hand-elsevier-journal

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

http://www.oandplibrary.org/al/1957_01_004.asp

https://jneuroengrehab.biomedcentral.com/articles/10.1186/s12984-018-0417-4

https://link.springer.com/article/10.1016%2 FS1672-6529%2816%2960377-3

https://www.sciencedirect.com/science/article/pii/S1672652916603773

http://wcms.inf.ed.ac.uk/ipab/slmc/research/undergraduate-and-msc-projects/improvingrobotic-prosthetic-hand-performance-throughgrasp-preshaping/KyranouThesis.pdf

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

file:///C:/Users/Ashutosh%20Pandey/Downloads/Bionic_prosthetic_hands_A_review_of_ present_techno.pdf

https://en.wikipedia.org/wiki/Prosthesis

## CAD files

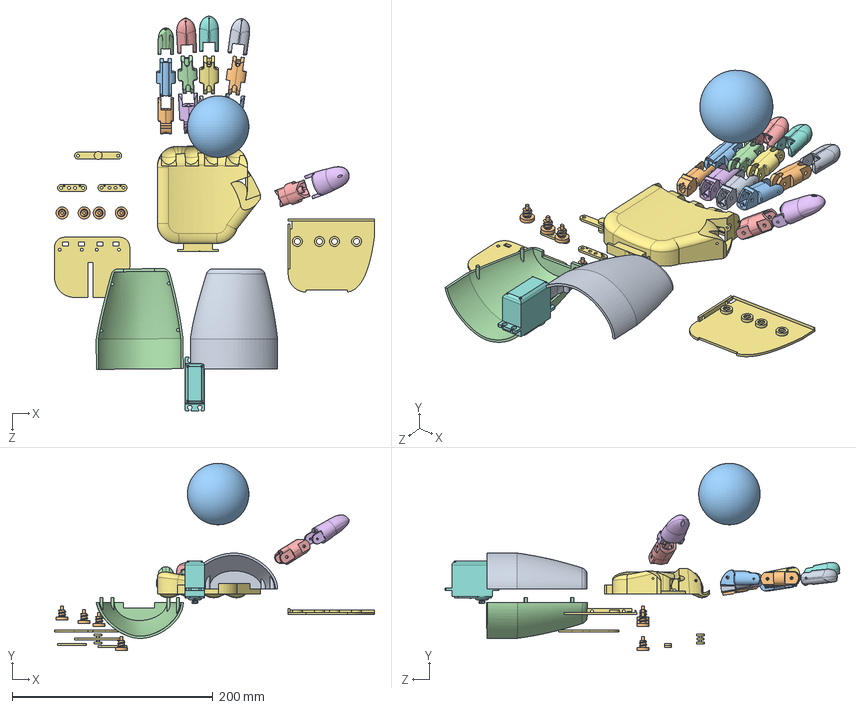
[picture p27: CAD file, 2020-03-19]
CAD Data/Modular Prosthetic Arm.SLDASM
318.7 x 186.6 x 393.0 mm
Index Finger Distal
Index Finger Middle
Index Finger Bottom Proximal
Ring Finger Middle
Ring Finger Distal
Ring Finger Bottom Proximal
Middle Finger Middle
Middle Finger Distal
Middle Finger Bottom Proximal
Pinky Finger Bottom Proximal
Pinky Finger Middle
Pinky Finger Distal
Thumb Middle
Thumb tip 2
Palm Frame Body x 6
Forearm2
Lock Screw x 4
Forearm1

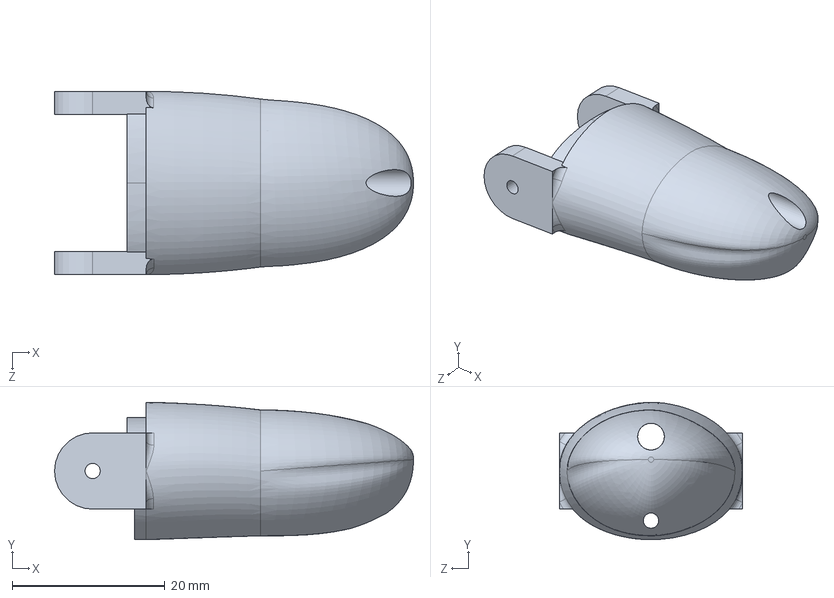
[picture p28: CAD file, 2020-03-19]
CAD Data/Final Model/Thumb tip 2.SLDPRT
47.0 x 18.0 x 24.0 mm

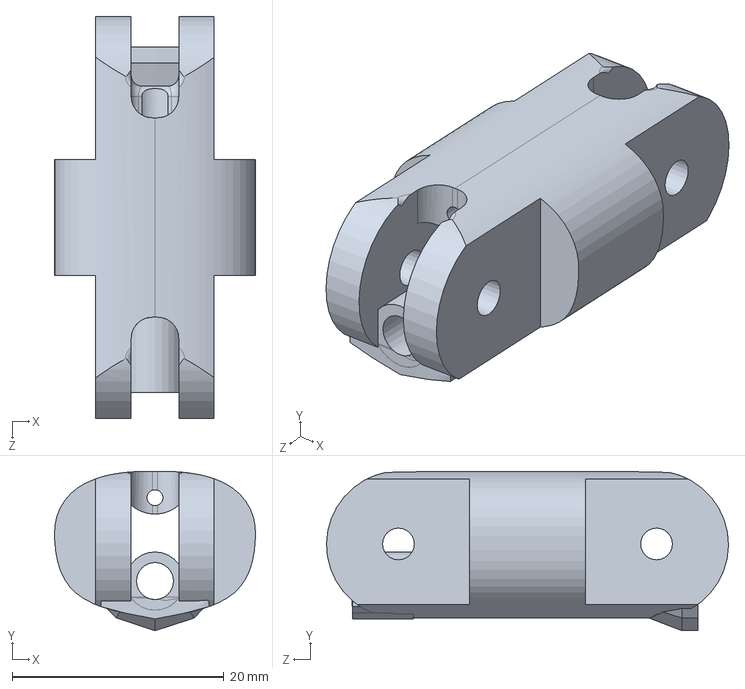
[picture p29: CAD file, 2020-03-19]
CAD Data/Final Model/Index Finger Middle.SLDPRT
19.0 x 15.1 x 38.0 mm

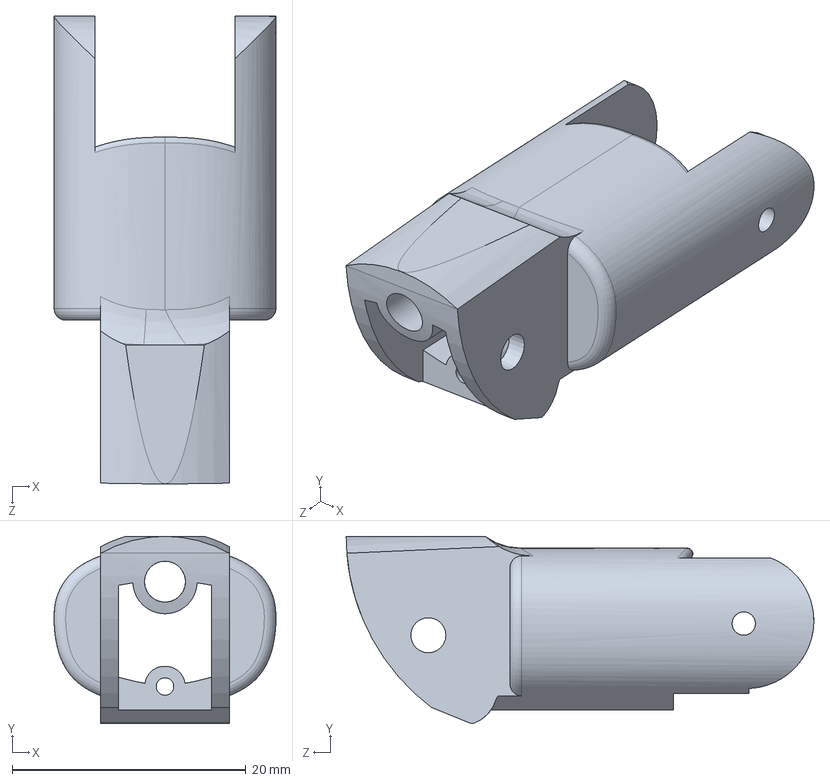
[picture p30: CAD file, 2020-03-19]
CAD Data/Final Model/Index Finger Bottom Proximal.SLDPRT
19.0 x 16.0 x 40.0 mm

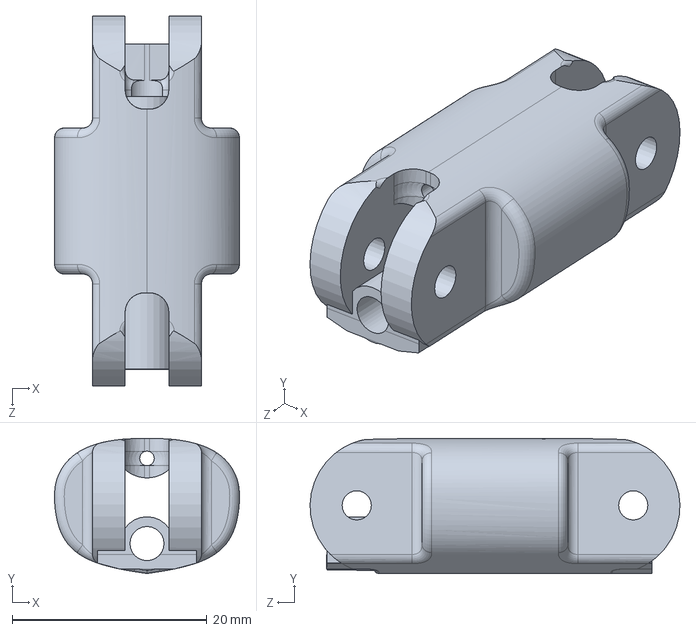
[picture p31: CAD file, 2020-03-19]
CAD Data/Final Model/Middle Finger Middle.SLDPRT
19.0 x 13.9 x 38.0 mm

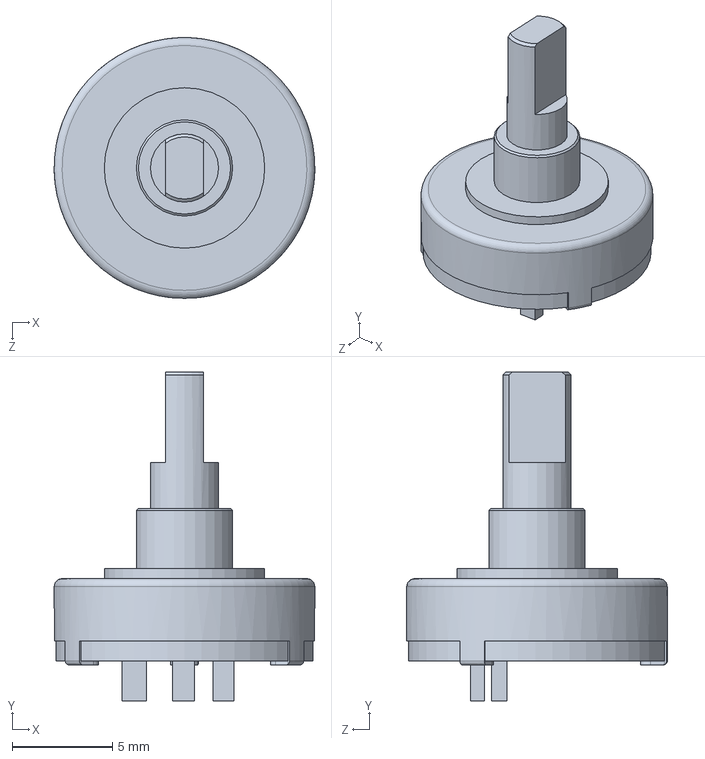
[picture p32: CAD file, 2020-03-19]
CAD Data/Final Model/TowerPro mg996r potentiometer.SLDPRT
13.0 x 16.4 x 13.0 mm

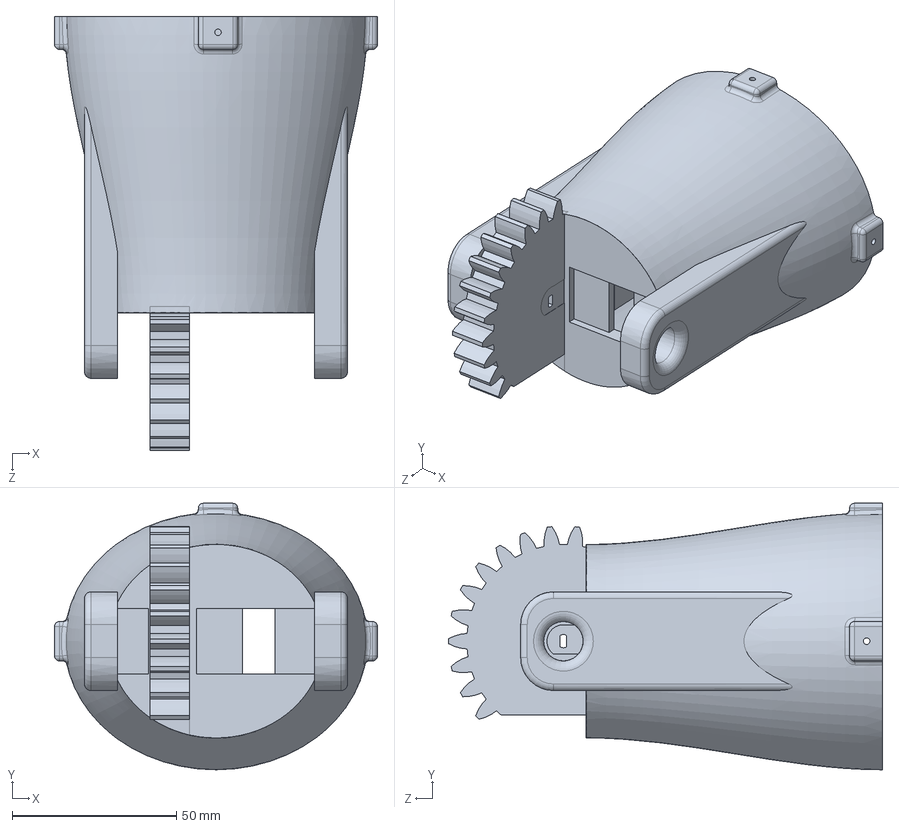
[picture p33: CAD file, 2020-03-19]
CAD Data/Final Model/Upper Forearm with Gear.SLDPRT
98.2 x 81.1 x 132.1 mm

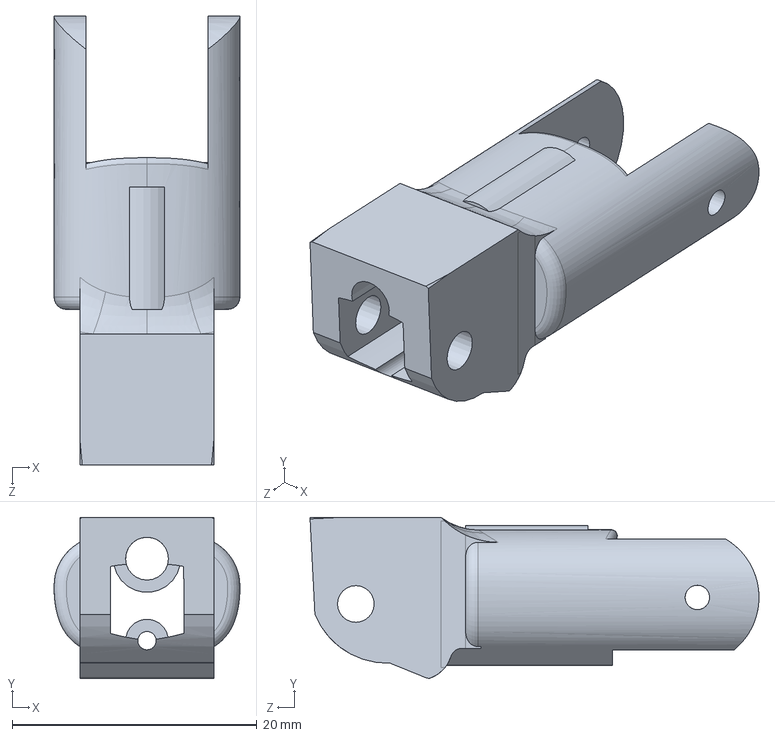
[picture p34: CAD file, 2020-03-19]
CAD Data/Final Model/Pinky Finger Bottom Proximal.SLDPRT
15.2 x 13.2 x 36.7 mm

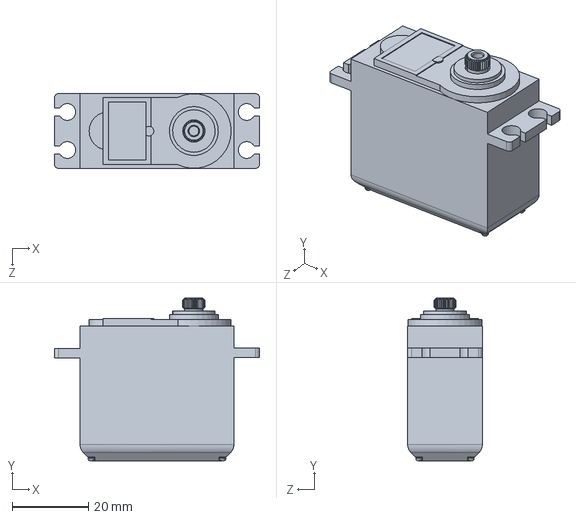
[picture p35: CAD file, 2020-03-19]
CAD Data/Final Model/Standard Servo.SLDPRT
53.7 x 42.6 x 19.6 mm

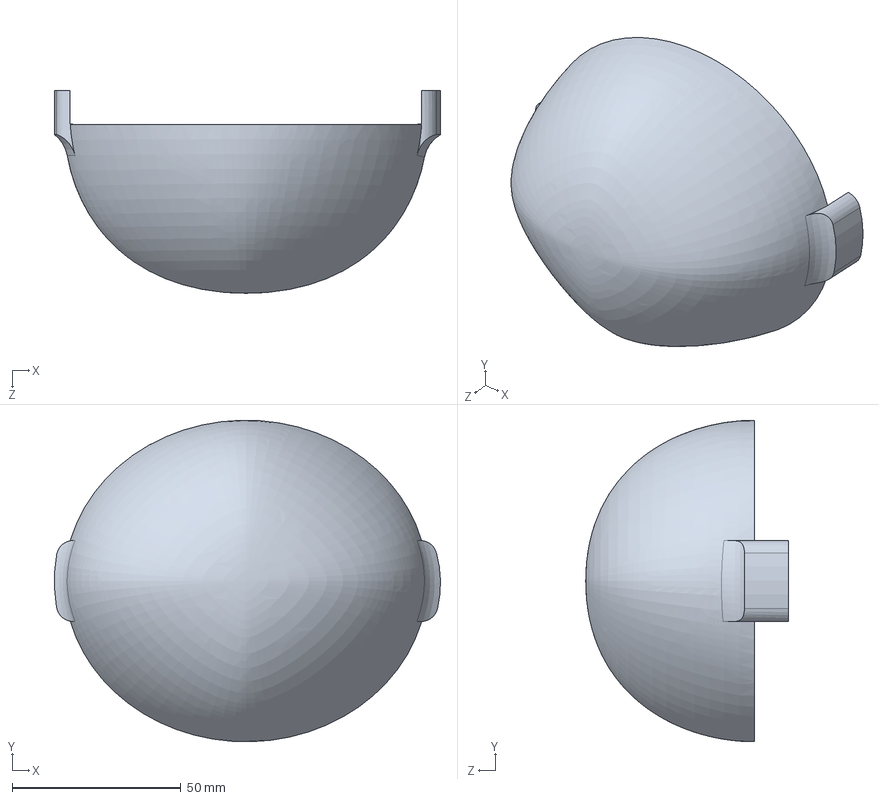
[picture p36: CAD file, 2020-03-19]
CAD Data/Final Model/Upper Bicep Cap.SLDPRT
114.3 x 95.2 x 60.0 mm

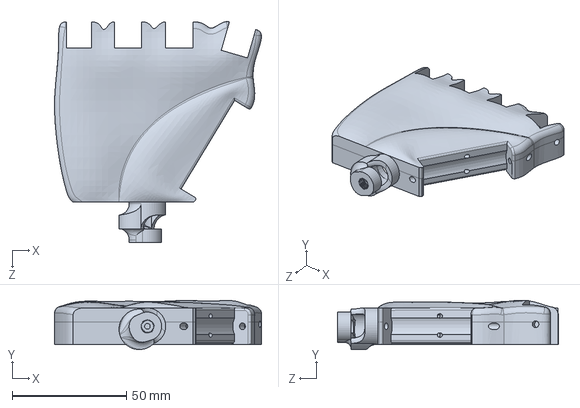
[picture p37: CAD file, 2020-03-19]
CAD Data/Final Model/Palm _ Optimised Connector.SLDPRT
90.8 x 21.5 x 96.9 mm

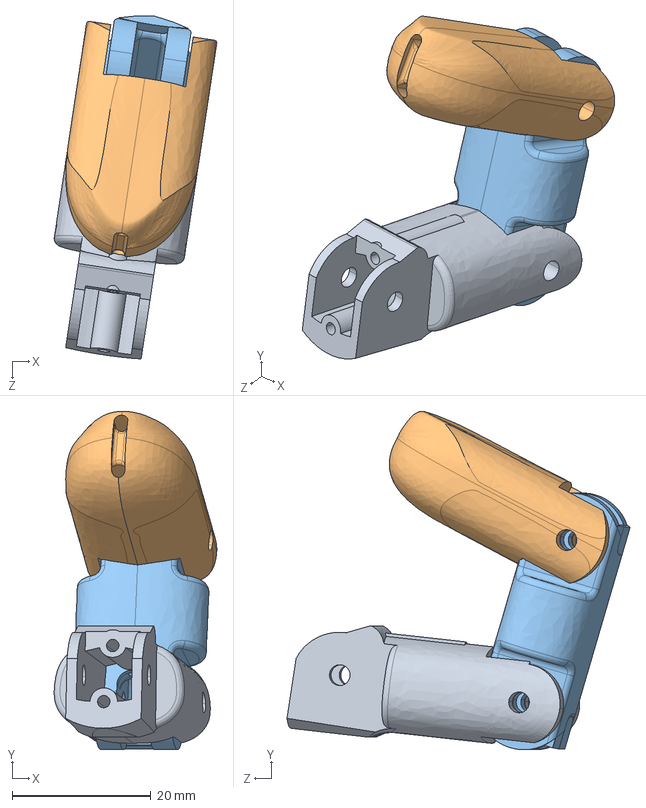
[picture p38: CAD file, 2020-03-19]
CAD Data/Final Model/Index retracted.STEP
23.4 x 48.8 x 49.4 mm
Index Finger Bottom Plus Cutout
Index Finger Tip
Index Finger Middle

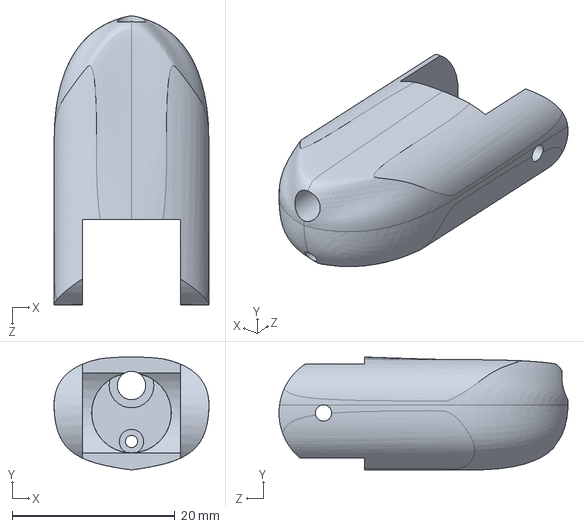
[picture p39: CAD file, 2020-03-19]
CAD Data/Final Model/Index Finger Distal.SLDPRT
19.0 x 13.9 x 35.5 mm

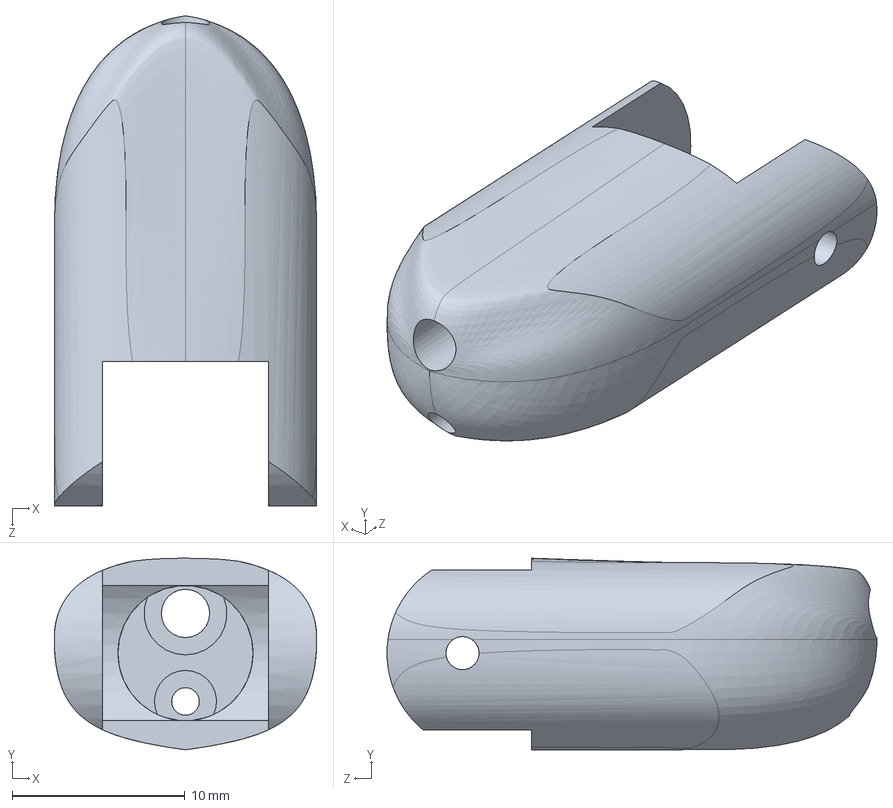
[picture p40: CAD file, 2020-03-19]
CAD Data/Final Model/Pinky Finger Distal.SLDPRT
15.2 x 11.1 x 28.4 mm

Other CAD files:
CAD Data/Final Model/Pinky Finger Middle.SLDPRT
CAD Data/Final Model/Index Finger Tip_Topology Study 1_deformed_body.sldprt
CAD Data/Final Model/Middle Finger Distal.SLDPRT
CAD Data/Final Model/Ring Finger Bottom Proximal.SLDPRT
CAD Data/Final Model/Forearm1.SLDPRT
CAD Data/Final Model/Forearm2.SLDPRT
CAD Data/Final Model/Forearm2.STL
CAD Data/Final Model/Full Assembly Exploded.SLDDRW
CAD Data/Final Model/Lock Screw.SLDPRT
CAD Data/Final Model/Middle Finger Bottom Proximal.SLDPRT
CAD Data/Final Model/Ring Finger Distal.SLDPRT
CAD Data/Final Model/Ring Finger Middle.SLDPRT
CAD Data/Final Model/Servo Horn.SLDPRT
CAD Data/Final Model/Thumb Lower.SLDPRT
CAD Data/Final Model/Thumb Middle.SLDPRT
